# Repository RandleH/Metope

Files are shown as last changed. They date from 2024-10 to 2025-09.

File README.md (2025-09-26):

# Metope

<p align="center"> 
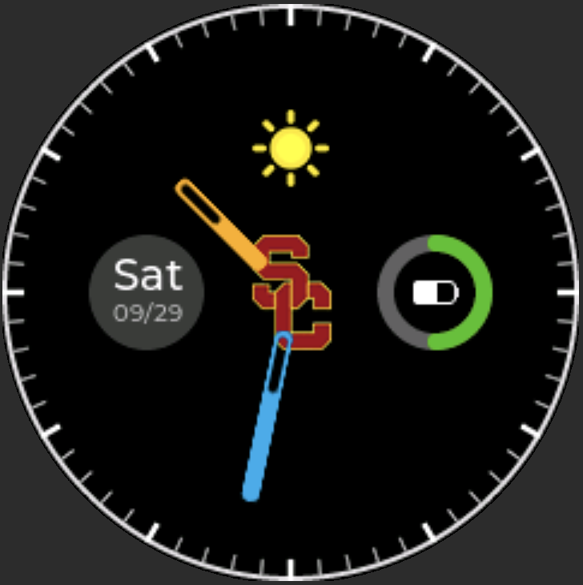
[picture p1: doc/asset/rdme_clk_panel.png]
rdme_clk_panel
    
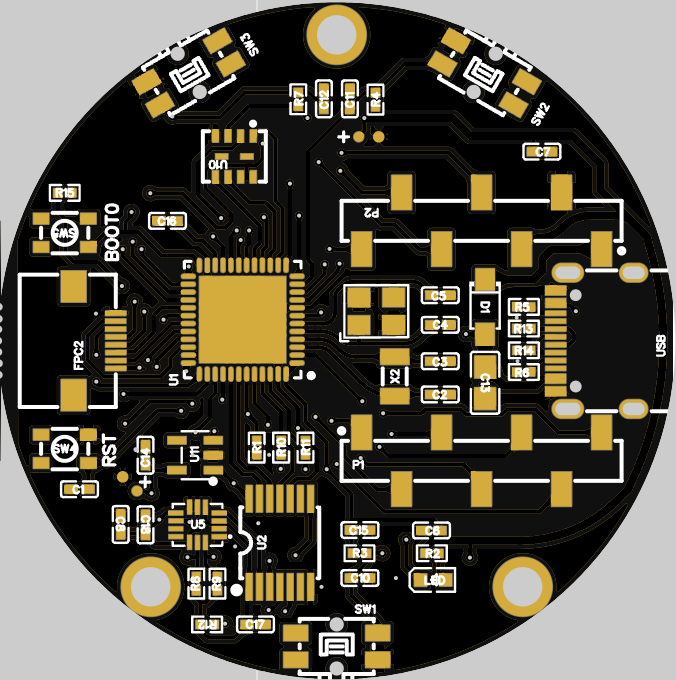
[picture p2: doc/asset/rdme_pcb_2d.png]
rdme_pcb_2d
   
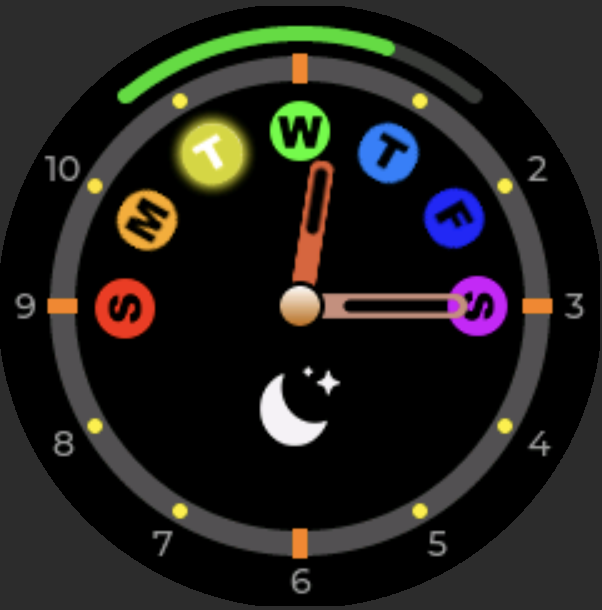
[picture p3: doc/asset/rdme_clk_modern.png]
rdme_clk_modern
    
</p>

Metope is a project for a smart digital watch system running on the STM32 target.

## Overview

<p align="center"> <img src="doc/asset/rdme_hierarchy.jpg" alt="rdme_clk_panel" ;" /> </p>

Color Capsule contributes to the firmware program. Grey rectangulars are only the auxiliary components.

## Requirement

- `CMake>=3.19.2`
- `make==3.81`
- `pyenv==2.6.8          (brew)`
- `pyserial==3.5         (pip package)`
- `pyserial-asyncio==0.6 (pip package)`

Metope project dosen't require to install the `arm-gnu-tool-chain` on the host system. Tool chain will be provided via `lib/arm-toolchain`

## Workspace Setup

Clone the workspace

```bash
git clone https://github.com/RandleH/Metope.git
```

This chapter only provides one of the recommended way to set up the project. For more details, please visit [here]().

Deploy the environment

```bash
source setup.env
```

> Target: `STM32F411CEU6`

Compile

```bash
sh rebuild.sh
```

The output files will be the following items:

- `build/model1.elf` - Executable Linkable File
- `build/model1.hex` - Hex file for USART download
- `build/model1.bin` - Compact binary to flash the target memory

## Compilation

Metope has a bash script for the convenience of compilation. Please take reference for `Compilation Configuration Zone` in `rebuild.sh`.

<p align="center"> <img src="doc/asset/rdme_config.jpg" alt="rdme_clk_panel" ;" /> </p>

Here are some typical configurations. Copy the command and replace the one in `rebuild.sh` in the `Compilation Configuration Zone`

### C Make Flag Table

| Keyword \ Allowed Value | 0 | 1 | 2 | Debug | Release |
| --- | --- | --- | ---- | ----- | --- |
| CMAKE_BUILD_TYPE | | | | $√$ | $√$ |
| LOG_LEVEL | **$√$** | $√$ | $√$  | | |
| QMI8658A | | **$\color{green}(√)$** | | | |
| QMI8658C | | $\color{green}(√)$ | | | |
| MPU6050 | | $\color{green}(√)$ | | | |
| UNIT_TEST | | $\color{cyan}(√)$ | | | |
| INCLUDE_TB_OS | $\color{cyan}[√]$ | $\color{cyan}[√]$ | | | |
| INCLUDE_TB_BSP | $\color{cyan}[√]$ | $\color{cyan}[√]$ | | | |
| INCLUDE_TB_CMN | $\color{cyan}[√]$ | $\color{cyan}[√]$ | | | |

### Environment Setup

#### STM32F411CEU6

>```bash
>source setup.env
>```
>
>Or 
>
>```bash
>source setup.env STM32F411CEU6
>```

#### STM32F405RGT6

```bash
source setup.env STM32F405RGT6
```

#### Native

```bash
source setup.env native
```

This native mode will use your local compiler to partially build the project. This is for the purpose of experiment to test non-machine dependent code.

Note that the main entrance of native program is different than others.

- Native Program: `${PRJ_TOP}/artifacts/main_native.cc`
- Target Program: `${PRJ_TOP}/artifacts/main_program.cc`
- Emulator Program: `${PRJ_TOP}/artifacts/main_emulator.cc`

### Firmware (Debug)

```bash
mkdir build
cd ./build
cmake -DCMAKE_BUILD_TYPE=<value> [-DLOG_LEVEL=<value>] .. && make -j12
```

> Example:
>
> ```
> cmake -DCMAKE_BUILD_TYPE=Debug -DLOG_LEVEL=2 .. && make -j12
> ```
>
> ```
> cmake -DCMAKE_BUILD_TYPE=Debug -DLOG_LEVEL=0 .. && make -j12
> ```

### Firmware (Release)

```bash
mkdir build
cd ./build
cmake -DCMAKE_BUILD_TYPE=Release .. && make -j12
```

### Test Bench (CI)

```bash
mkdir build
cd ./build
cmake -DCMAKE_BUILD_TYPE=Debug -DUNIT_TEST=1 -DINCLUDE_TB_BSP=1 -DINCLUDE_TB_CMN=1 .. && make -j12
```

## Debug

### Vscode

Step 0: Always deploy the environment first.

> ```bash
> source setup.env
> ```
>
> The `.vscode` will be updated here depending on your OS.

Step 1: Install the Vscode extension `Cortex-Debug`

Step 2: Install `J-Link` tools

>```bash
>brew install --cask segger-jlink
>```

Step 3: Select a specific debugging mode

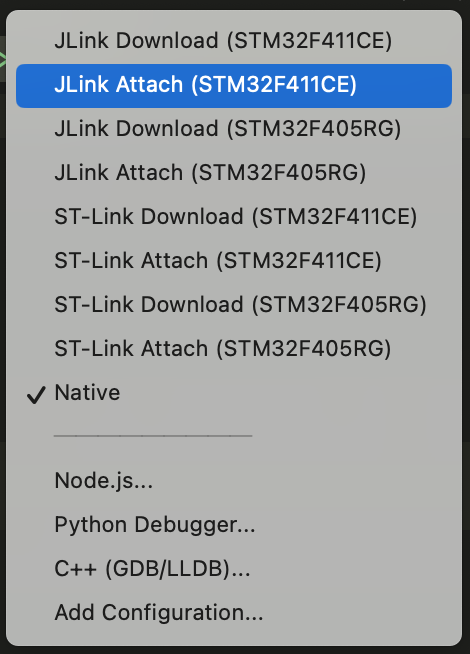
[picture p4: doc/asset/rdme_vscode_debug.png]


>- `JLink Download` - Download the program to target. You need to compile the project first.
>
>- `JLink Attach` - Attach to the program without downloading. Again you need to compile first.
>
>- `STLink Download` - Same as the J-Link but use ST-Link Port
>
>- `STLink Attach` - Same as the J-Link but use ST-Link Port
>
>- `Native` - This will call native cppdbg. Make sure you have your local compiler installed
>
>- `Emulator` - Run the program via qemu emulator environment

## Analog Clock

The angle of hour needle and minute needle has the following property.

Let $\alpha$ be the hour needle angle and $\beta$ be the minute needle angle, where $\alpha,\beta \in [0:3599]$.

$$
\frac{\beta}{12}= \Delta\alpha
$$

> (1)

$$
\Delta\alpha=\alpha \mod{\frac{3600}{12}}
$$

> (2)

Note  $\xi_{\alpha}$ and $\xi_{\beta}$ be the remainder of escaped time in microseconds. Then

$$
t_{\Delta\alpha} = \Delta\alpha \cdot12000 + \xi_{\alpha}
$$
> (3) where $t_{\Delta\alpha}$ is represented in microseconds

$$
t_{\beta} = \beta \cdot 1000 + \xi_{\beta}
$$
> (4) where $t_{\Delta\beta}$ is represented in microseconds. 

$$
t_{\Delta\alpha} = t_{\Delta\beta}
$$

> (5) The escaped time should always the same.

Therefore `(2)` `(3)` `(4)` `(5)` $\Rightarrow$ `(6)`.

$$
12000 \cdot \left( \alpha \mod{\frac{3600}{12}} \right) + \xi_{\alpha} = \beta \cdot 1000 + \xi_{\beta}
$$

> (6)

Check more details on [desmos](https://www.desmos.com/calculator/9qkivl2gf6),. A live diagram explains a lot.

## Code Conduct

I'd appreciate everybody's efforts to maintain a good, high quality coding environment. Good coding habit increased readability and minimized the bugs. In this project, there are a set of rules on code format.

### Code Section

```c
/* ************************************************************************** */
/*                                    XXXX                                    */
/* ************************************************************************** */
```

### Function

```c
/**
 * @brief Description
 * @param [in]    arg1 - xxxx
 * @param [inout] arg2 - xxxx
 * @param [out]   arg3 - xxxx
 * @return xxxx
 */
int foo( int arg1, int arg2, int arg3){
  // body //
}
```

> Each function must have `brief` | `param` (if exists) | `return` (if exists) in doxygen style.

### Safe Zone Banner

```c
///////////////////////////////////////////////////////////////
/////////////////////// Safe Zone Start ///////////////////////

//////////////////////// Safe Zone End ////////////////////////
///////////////////////////////////////////////////////////////
```

### File Header

```c
/**
 ******************************************************************************
 * @file    xxxx.c
 * @author  RandleH
 * @brief   xxxx
 ******************************************************************************
 * @attention
 *
 * Copyright (c) 2022 RandleH.
 * All rights reserved.
 *
 * This software component is licensed by RandleH under BSD 3-Clause license,
 * the "License"; You may not use this file except in compliance with the
 * License. You may obtain a copy of the License at:
 *                        opensource.org/licenses/BSD-3-Clause
 *
 ******************************************************************************
*/
```

### C Compilation Indication

```c++
#ifdef __cplusplus
extern "C"{
#endif

#ifdef __cplusplus
}
#endif
```

## Python Environment Setup

### Create pyenv folder

If the following directory doesn't exist, make one.
```
mkdir ~/.pyenv
mkdir ~/.pyenv/versions/
```

### Link Python
Link python package to the one installed by brew
```
ln -s $(brew --cellar python)/* ~/.pyenv/versions/
```

### Install Python
It's better to install the python via pyenv. More user friendly when switching to either local or global.
```
brew install libxml2 libxslt
pyenv install 3.11.5
```

## Lesson Learnt

Sep 3rd, 2025
>Register SR got cleared when inserting a breakpoint in the handler. Consequently the system can not recognize the new RX message because the SR register was cleared.
>
>Do not add the break point ahead of the program reading the register. Because reading the register value means something else in the embedded system. It may clear the internal bits by hardware. Your debugger will sceiently read those value causing register value cleared and this may impact your callflow.

## Utility

- [**Online GDB**](https://www.onlinegdb.com/)
- [**Simulator**](https://wokwi.com)
- [**Hex Viewer**](https://hexed.it)

## Reference

- [**Datasheet - SpeedStudio Round LCD V1.1** ](https://files.seeedstudio.com/wiki/round_display_for_xiao/SeeedStudio_Round_Display_for_XIAO_v1.1_SCH_230407.pdf)
- [**Programming Manual - STM32F4**](https://www.st.com/resource/en/programming_manual/pm0214-stm32-cortexm4-mcus-and-mpus-programming-manual-stmicroelectronics.pdf)
- [**Reference Manual - STM32F405RGT6**](https://www.st.com/resource/en/reference_manual/dm00031020-stm32f405-415-stm32f407-417-stm32f427-437-and-stm32f429-439-advanced-arm-based-32-bit-mcus-stmicroelectron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)
- [**Reference Manual - STM32F411CEU6**](https://www.st.com/resource/en/reference_manual/rm0383-stm32f411xce-advanced-armbased-32bit-mcus-stmicroelectronics.pdf)
- [**Datasheet - STM32F405RGT6**](https://www.st.com/resource/en/datasheet/stm32f405rg.pdf)
- [**Datasheet - STM32F411CEU6**](https://www.st.com/resource/en/datasheet/stm32f411ce.pdf)
- [**Datasheet - QMI8658A**](https://www.qstcorp.com/upload/pdf/202301/13-52-25%20QMI8658A%20Datasheet%20Rev%20A.pdf)
- [**Datasheet - W25Q32**](https://mm.digikey.com/Volume0/opasdata/d220001/medias/docus/5059/W25Q32JV_RevI_5-4-21.pdf)

- [**Datasheet - LSF0204x**](https://www.ti.com/lit/ds/symlink/lsf0204d.pdf?ts=1733701959935)

- [**IAR Compiler Guide**](https://wwwfiles.iar.com/AVR/webic/doc/EWAVR_CompilerGuide.pdf)

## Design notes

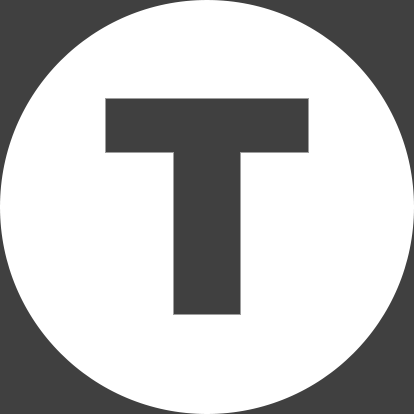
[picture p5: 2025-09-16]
sqlstudio/assets/T.png

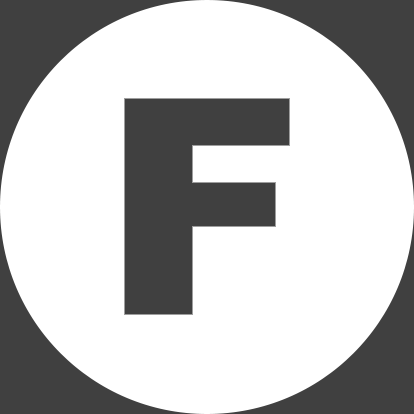
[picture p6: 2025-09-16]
sqlstudio/assets/F.png

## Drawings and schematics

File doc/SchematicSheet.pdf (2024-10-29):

PB15

# NRST PC¹⁴

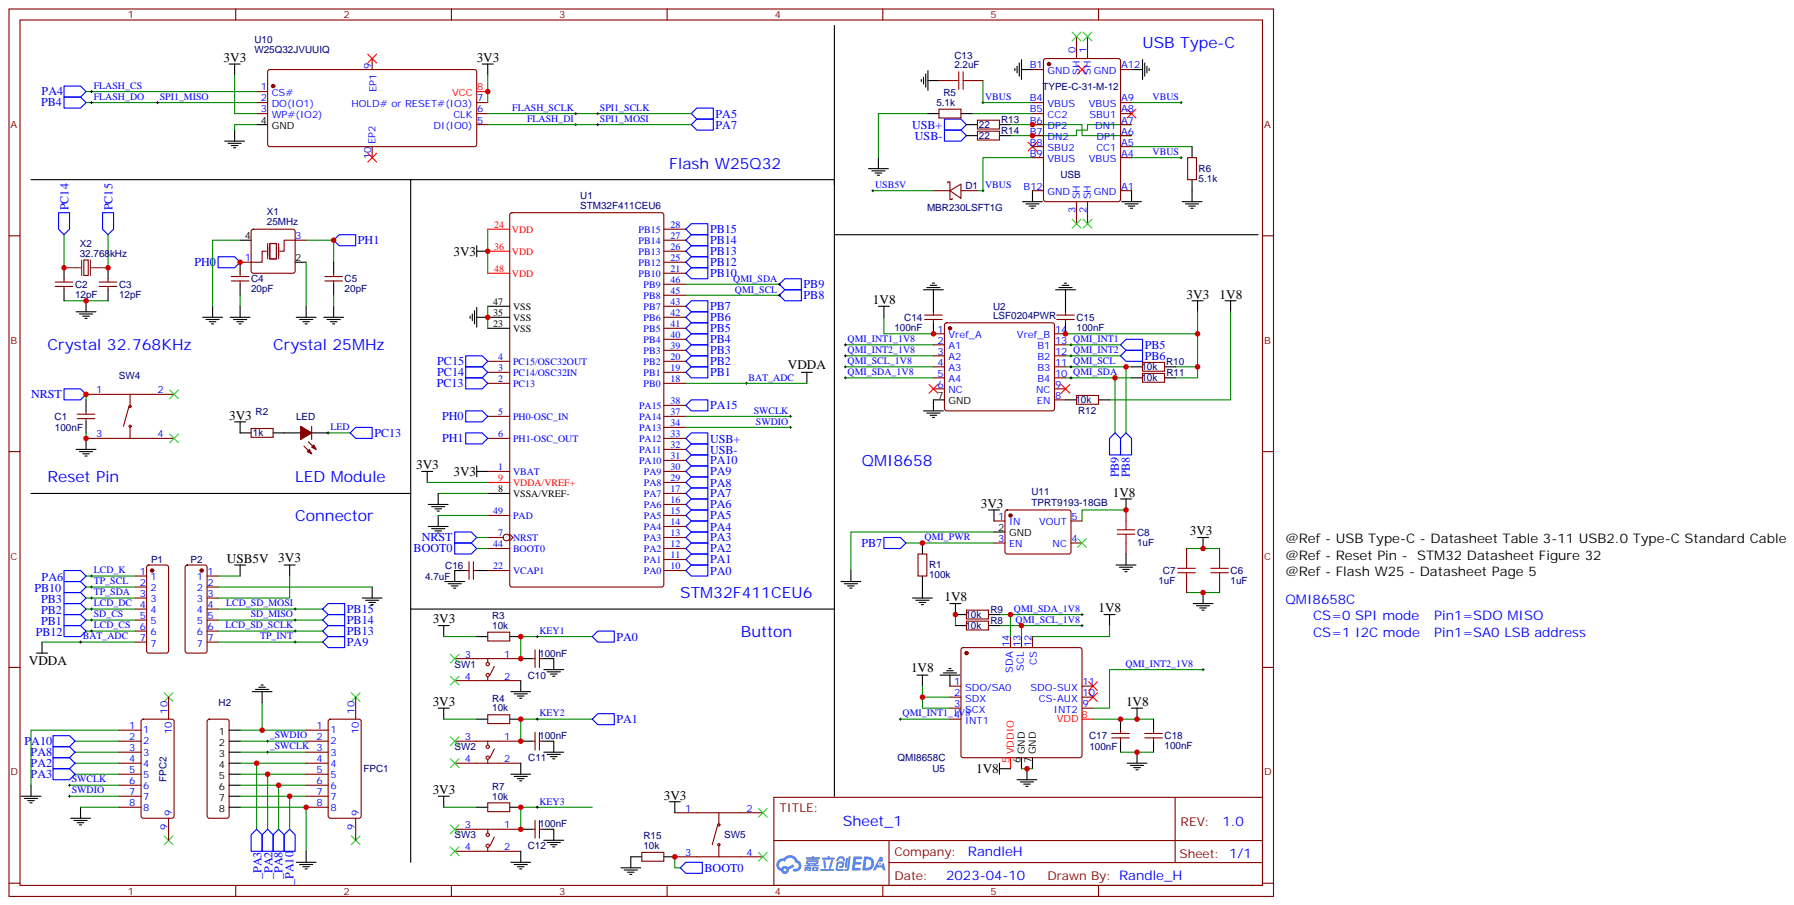
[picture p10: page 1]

@Ref - USB Type-C - Datasheet Table 3-11 USB2.0 Type-C Standard Cable
@Ref - Reset Pin - STM32 Datasheet Figure 32
@Ref - Flash W25 - Datasheet Page 5
QMI8658C
CS=0 SPI mode

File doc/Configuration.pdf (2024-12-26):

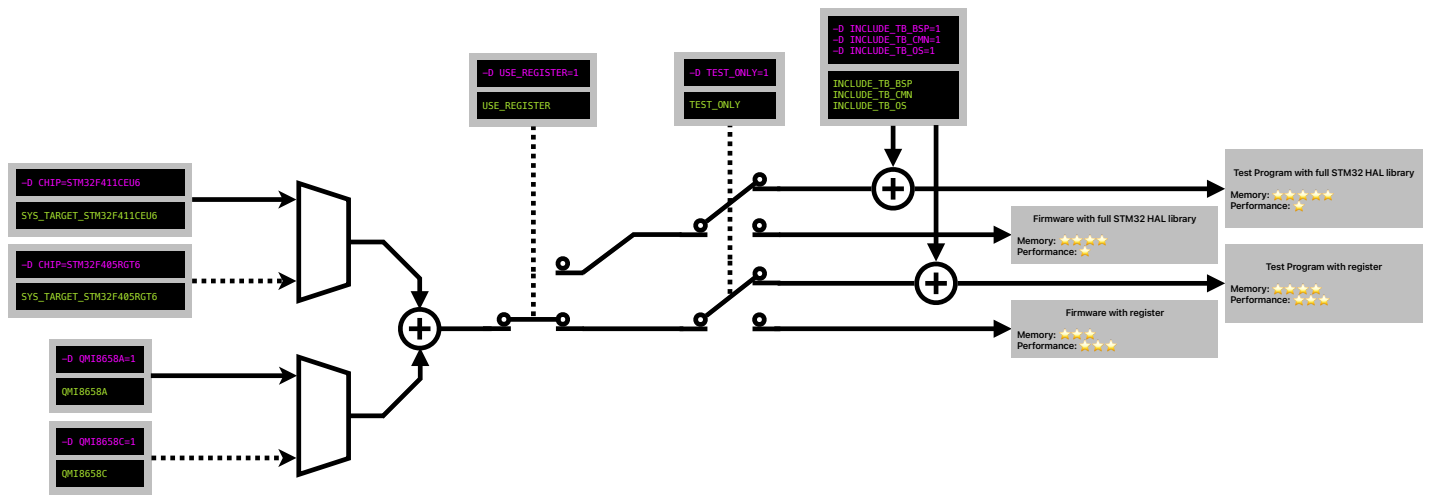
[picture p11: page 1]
-D CHIP=STM32F411CEU6; SYS_TARGET_STM32F411CEU6; -D CHIP=STM32F405RGT6; SYS_TARGET_STM32F405RGT6; -D USE_REGISTER=1; USE_REGISTER; -D TEST_ONLY=1; TEST_ONLY; -D QMI8658A=1; QMI8658A; -D QMI8658C=1; QMI8658C; -D INCLUDE_TB_BSP=1 -D INCLUDE_TB_CMN=1 -D INCLUDE_TB_OS=1; INCLUDE_TB_BSP INCLUDE_TB_CMN INCLUDE_TB_OS; Memory: ⭐ ⭐ ⭐ ⭐ ⭐ Performance: ⭐; Memory: ⭐ ⭐ ⭐ ⭐ Performance: ⭐; Memory: ⭐ ⭐ ⭐ ⭐ Performance: ⭐ ⭐ ⭐; Memory: ⭐ ⭐ ⭐ Performance: ⭐ ⭐ ⭐

Test Program with full STM32 HAL library

Firmware with full STM32 HAL library

Test Program with register

Firmware with register

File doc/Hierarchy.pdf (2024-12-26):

# cmn

# bsp

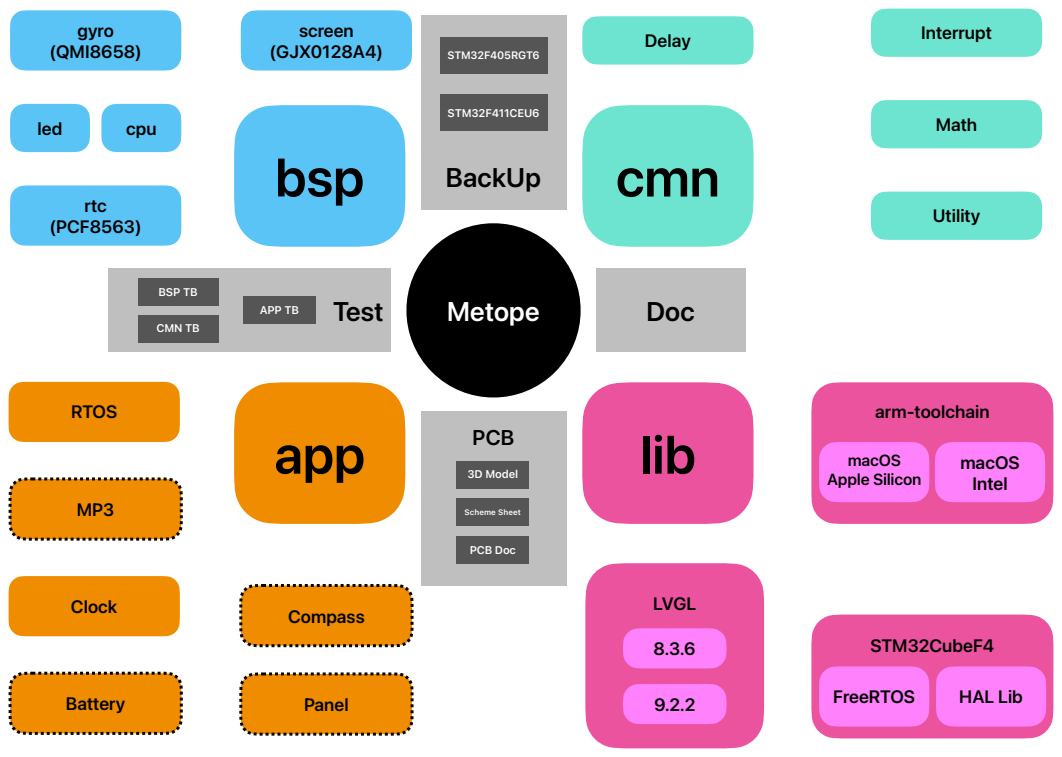
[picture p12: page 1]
STM32CubeF4; arm-toolchain; LVGL; lib; FreeRTOS; HAL Lib; macOS Apple Silicon; macOS Intel; Delay; Interrupt; Math; Utility; cpu; gyro (QMI8658); led; rtc (PCF8563); screen (GJX0128A4); app; RTOS; Clock; Compass; Battery; Panel; Test; Metope; Doc; BackUp; PCB; BSP TB; CMN TB; APP TB; STM32F405RGT6; STM32F411CEU6; 3D Model; Scheme Sheet; PCB Doc

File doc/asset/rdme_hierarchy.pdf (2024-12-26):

# cmn

# bsp

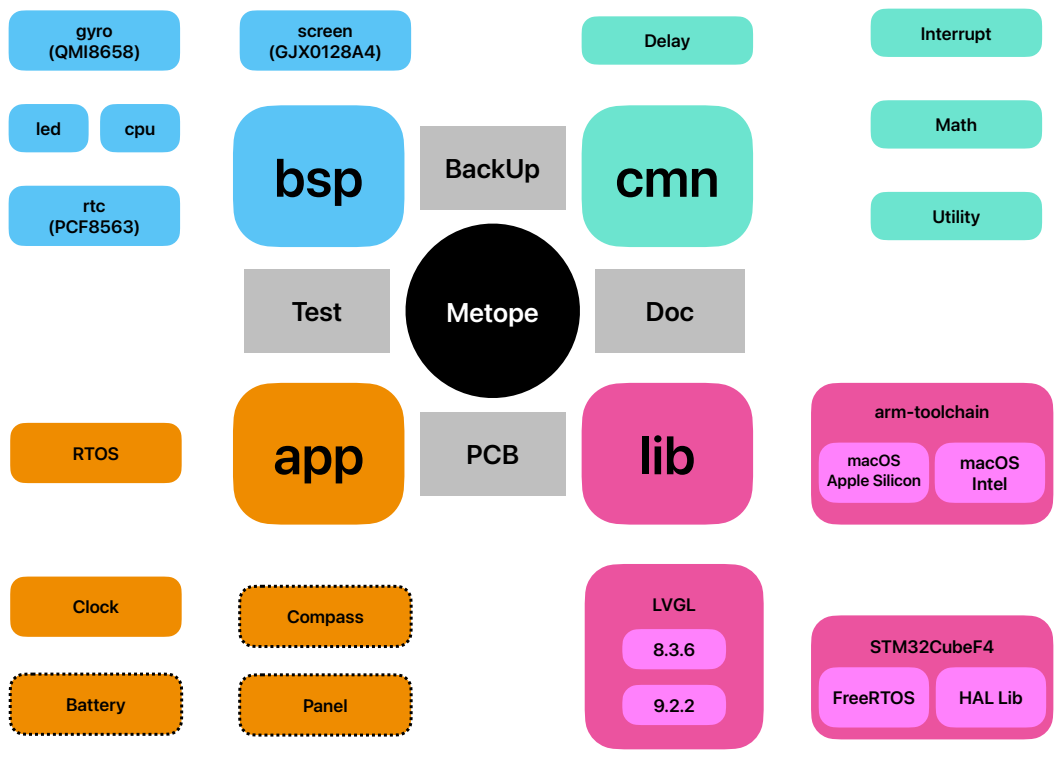
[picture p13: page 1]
STM32CubeF4; arm-toolchain; LVGL; lib; FreeRTOS; HAL Lib; macOS Apple Silicon; macOS Intel; Delay; Interrupt; Math; Utility; cpu; gyro (QMI8658); led; rtc (PCF8563); screen (GJX0128A4); RTOS; app; Clock; Compass; Battery; Panel; Test; Metope; Doc; BackUp; PCB

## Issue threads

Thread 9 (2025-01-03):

Clock Pattern Mismatched

RandleH, 2025-01-03:
See details in the `app_gui.c`
> ```
> ASSERT( minute_in_ms_total == delta_hour_in_ms_total, "Needle Pattern Mismatched");
> ```

From the trace log, the minute and hour degrees variable was accidentally overwritten in somewhere else.

```
ms=75 H_rem=5075 M_rem=75 H_deg=3106 M_deg=1277 h'_ms=1272000 m_ms=1277000 H'_ms=1277075 M_ms=1277075
ms=75 H_rem=5150 M_rem=150 H_deg=3106 M_deg=1277 h'_ms=1272000 m_ms=1277000 H'_ms=1277150 M_ms=1277150
ms=75 H_rem=5225 M_rem=225 H_deg=3106 M_deg=1277 h'_ms=1272000 m_ms=1277000 H'_ms=1277225 M_ms=1277225
ms=75 H_rem=5300 M_rem=300 H_deg=3106 M_deg=1277 h'_ms=1272000 m_ms=1277000 H'_ms=1277300 M_ms=1277300
ms=75 H_rem=5375 M_rem=375 H_deg=3106 M_deg=1277 h'_ms=1272000 m_ms=1277000 H'_ms=1277375 M_ms=1277375
ms=75 H_rem=5450 M_rem=450 H_deg=3106 M_deg=1277 h'_ms=1272000 m_ms=1277000 H'_ms=1277450 M_ms=1277450
ms=75 H_rem=5525 M_rem=525 H_deg=3106 M_deg=1277 h'_ms=1272000 m_ms=1277000 H'_ms=1277525 M_ms=1277525
ms=75 H_rem=5600 M_rem=600 H_deg=3106 M_deg=1277 h'_ms=1272000 m_ms=1277000 H'_ms=1277600 M_ms=1277600
ms=75 H_rem=5675 M_rem=675 H_deg=3106 M_deg=1277 h'_ms=1272000 m_ms=1277000 H'_ms=1277675 M_ms=1277675
ms=75 H_rem=5750 M_rem=750 H_deg=3106 M_deg=1277 h'_ms=1272000 m_ms=1277000 H'_ms=1277750 M_ms=1277750
ms=75 H_rem=5825 M_rem=825 H_deg=3106 M_deg=1277 h'_ms=1272000 m_ms=1277000 H'_ms=1277825 M_ms=1277825
ms=75 H_rem=5900 M_rem=900 H_deg=3106 M_deg=1277 h'_ms=1272000 m_ms=1277000 H'_ms=1277900 M_ms=1277900
ms=75 H_rem=5975 M_rem=975 H_deg=3106 M_deg=1277 h'_ms=1272000 m_ms=1277000 H'_ms=1277975 M_ms=1277975
ms=75 H_rem=6050 M_rem=50 H_deg=3106 M_deg=1278 h'_ms=1272000 m_ms=1278000 H'_ms=1278050 M_ms=1278050
ms=75 H_rem=6125 M_rem=125 H_deg=3106 M_deg=1277 h'_ms=1272000 m_ms=1277000 H'_ms=1278125 M_ms=1277125

Assertion@/Users/yuanjiqiu/Desktop/Metope/app/app_gui.c:339
Needle Pattern Mismatched
```

The `M_deg` was unexpectedly change back to `1277`.

Checked the angle calculation. Result was correct.

Clock pattern simulation is available on [here](https://www.desmos.com/calculator/yhxkqm7rup)

RandleH, 2025-01-04:
## Analysis

Issue was caused by unprotected shared resource designed.

We have `app_gui_update_modulo()` and `app_gui_clock_main()` running in two threads.
Both functions have R/W access to the clock parameters.

Note that in `app_gui_update_modulo()`:
```
pClient->_degree_hour %= 3600
pClient->_degree_minute %= 3600
```
Modulo is NOT an atomic operation.

Besides `app_gui_update_modulo ()` is on the idle thread, which would have the lowest priority in tasks.

## Solution

- For each clock style, create `init()` | `inc()` | `set()` | `idle()` | `deinit()` methods.
-- `idle()` will run on the FreeRTOS idle task.
- For clock private parameters, it will be allocated on the `p_anything` pointer.
- Add mutex for clock private parameters.

Closed 2025-01-04.

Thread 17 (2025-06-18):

Add Sleep Mode and Low Power Mode

RandleH, 2025-06-18:
- STM32 Support the WakeUp Key A0
- Deep sleep mode. Only the external RTC module is running.

RandleH, 2025-06-20:
Entering low-power mode:
- Disable unnecessary peripherals.
- Gating the clocks to the APBx and AHBx peripherals when they are unused.
- Slowing down the system clocks
- Low-power modes are entered by the MCU by executing the WFI (Wait For Interrupt), or WFE (Wait for Event) instructions, or when the SLEEPONEXIT bit in the Cortex®-M4 with FPU System Control register is set on Return from ISR.

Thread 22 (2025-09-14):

Noise from USART can cause an assertion

RandleH, 2025-09-14:
**Issue**
- The command box will parse the string buffer after the rx interrupt even when a noise occurred.

**Action Item**
- Please add the error code handler for this.
- Make assertion for the invalid command only in DEBUG mode.

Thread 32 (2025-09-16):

App cmdbox message process bugs.

RandleH, 2025-09-16:
It is per interrupt per character. Each ISR call will unblock the cmdbox_main and flush the buffer W/WO checking the new_msg or not.

RandleH, 2025-09-17:
```
ASSERT( (*cmd_end == '\0'), "Command string must be null terminated!!");
```

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

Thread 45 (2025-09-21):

Add GDB listener script

RandleH, 2025-09-21:
Once connected the target, add GDB listener to trace the status. If watch dog is missing or hardfault handler was detected, generate the core dump and commit to a new branch automatically.

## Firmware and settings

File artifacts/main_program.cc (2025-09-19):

/**
 ******************************************************************************
 * @file    main_program.cc
 * @author  RandleH
 * @brief   Main program entrance
 ******************************************************************************
 * @attention
 *
 * Copyright (c) 2022 RandleH.
 * All rights reserved.
 *
 * This software component is licensed by RandleH under BSD 3-Clause license,
 * the "License"; You may not use this file except in compliance with the
 * License. You may obtain a copy of the License at:
 *                        opensource.org/licenses/BSD-3-Clause
 *
 ******************************************************************************
*/


/* ************************************************************************** */
/*                                  Includes                                  */
/* ************************************************************************** */
#include "init.h"
#include "global.h"
#include "assert.h"
#include "trace.h"
#include "cmn_type.h"
#include "bsp_led.h"
#include "app_rtos.h"
#include "cmn_delay.h"


#ifdef __cplusplus
extern "C"{
#endif

int main(int argc, char *argv[]){
  
  /**
   * @note
   *  Hardware Initialization
   *  @cpu: CortexM4 STM32F411CEU6 96MHz
   *  @timer: SYSTICK=84MHz APB1=96MHz APB2=96MHz 
   *  @periphral: AHB=96MHz APB1=48MHz APB2=96MHz USB=48MHz HSE=25MHz LSE=32.768KHz
   * 
   *  @cpu: CortexM4 STM32F405RGT6 84MHz
   *  @timer: SYSTICK=84MHz APB1=84MHz APB2=84MHz 
   *  @periphral: AHB=84MHz APB1=42MHz APB2=84MHz HSE=25MHz LSE=32.768KHz
   * 
  */
  hw_init();
  data_init();
  bsp_init();
  app_init();
  os_init();

  TRACE_INFO("System boot completed.");

#if 1
  {
    const volatile uint32_t REG_SCB_CPUID = SCB->CPUID;
    TRACE_DEBUG("Processor Manufacturer Info:");
    TRACE_DEBUG("+------------------------------------------------------+");
    TRACE_DEBUG("| Implementer | Variant | Constant | PartNo | Revision |");
    TRACE_DEBUG("|-------------+---------+----------+--------+----------|");
    TRACE_DEBUG("| 0x%02X        | 0x%02X    | 0x%01X      | 0x%03X  | 0x%01X      |",\
      ((REG_SCB_CPUID & SCB_CPUID_IMPLEMENTER_Msk ) >> SCB_CPUID_IMPLEMENTER_Pos ),\
      ((REG_SCB_CPUID & SCB_CPUID_VARIANT_Msk     ) >> SCB_CPUID_VARIANT_Pos     ),\
      ((REG_SCB_CPUID & SCB_CPUID_ARCHITECTURE_Msk) >> SCB_CPUID_ARCHITECTURE_Pos),\
      ((REG_SCB_CPUID & SCB_CPUID_PARTNO_Msk      ) >> SCB_CPUID_PARTNO_Pos      ),\
      ((REG_SCB_CPUID & SCB_CPUID_REVISION_Msk    ) >> SCB_CPUID_REVISION_Pos    ) \
    );
    TRACE_DEBUG("+------------------------------------------------------+");
    TRACE_DEBUG("\n");
    UNUSED(REG_SCB_CPUID);
  }
#endif

#if 1
  {
    const volatile uint32_t REG_SCB_AIRCR = SCB->AIRCR;
    TRACE_DEBUG("Application Interrupt Reset Control Register:");
    TRACE_DEBUG("\tis_little_endian         %d", ((REG_SCB_AIRCR & SCB_AIRCR_ENDIANESS_Msk) >> SCB_AIRCR_ENDIANESS_Pos));
    TRACE_DEBUG("\tinterrupt_priority_group %d", ((REG_SCB_AIRCR & SCB_AIRCR_PRIGROUP_Msk) >> SCB_AIRCR_PRIGROUP_Pos));
    TRACE_DEBUG("\n");
  }
#endif

#if 1
  {
    const volatile uint32_t *REG_NVIC_ISER = NVIC->ISER;
    TRACE_DEBUG("Nested Vectored Interrupt Controller:");
    TRACE_DEBUG("\tis_irq_enabled   %d", (0 == __get_PRIMASK()));
    TRACE_DEBUG("\tUSART1_IRQn      %d", (0 != (REG_NVIC_ISER[USART1_IRQn     >> 5] & (1 << (USART1_IRQn     & 0x1F)))));
    TRACE_DEBUG("\tWWDG_IRQn        %d", (0 != (REG_NVIC_ISER[WWDG_IRQn       >> 5] & (1 << (WWDG_IRQn       & 0x1F)))));    /*!< Window WatchDog Interrupt                                         */
    TRACE_DEBUG("\tPVD_IRQn         %d", (0 != (REG_NVIC_ISER[PVD_IRQn        >> 5] & (1 << (PVD_IRQn        & 0x1F)))));    /*!< PVD through EXTI Line detection Interrupt                         */
    TRACE_DEBUG("\tTAMP_STAMP_IRQn  %d", (0 != (REG_NVIC_ISER[TAMP_STAMP_IRQn >> 5] & (1 << (TAMP_STAMP_IRQn & 0x1F)))));    /*!< Tamper and TimeStamp interrupts through the EXTI line             */
    TRACE_DEBUG("\tRTC_WKUP_IRQn    %d", (0 != (REG_NVIC_ISER[RTC_WKUP_IRQn   >> 5] & (1 << (RTC_WKUP_IRQn   & 0x1F)))));    /*!< RTC Wakeup interrupt through the EXTI line                        */
    TRACE_DEBUG("\tFLASH_IRQn       %d", (0 != (REG_NVIC_ISER[FLASH_IRQn      >> 5] & (1 << (FLASH_IRQn      & 0x1F)))));    /*!< FLASH global Interrupt                                            */
    TRACE_DEBUG("\tRCC_IRQn         %d", (0 != (REG_NVIC_ISER[RCC_IRQn        >> 5] & (1 << (RCC_IRQn        & 0x1F)))));    /*!< RCC global Interrupt                                              */
    TRACE_DEBUG("\tUSART2_IRQn      %d", (0 != (REG_NVIC_ISER[USART2_IRQn     >> 5] & (1 << (USART2_IRQn     & 0x1F)))));
    TRACE_DEBUG("\tEXTI15_10_IRQn   %d", (0 != (REG_NVIC_ISER[EXTI15_10_IRQn  >> 5] & (1 << (EXTI15_10_IRQn  & 0x1F)))));
    TRACE_DEBUG("\tTIM2_IRQn        %d", (0 != (REG_NVIC_ISER[TIM2_IRQn       >> 5] & (1 << (TIM2_IRQn       & 0x1F)))));
    TRACE_DEBUG("\n");
  }
#endif

#if 1
  {
    const volatile uint32_t REG_RCC_PLLCFGR = RCC->PLLCFGR;
    const volatile uint32_t REG_RCC_CFGR    = RCC->CFGR;
    
    uint32_t PLL_SRC = ((REG_RCC_PLLCFGR & RCC_PLLCFGR_PLLSRC_Msk) >> RCC_PLLCFGR_PLLSRC_Pos);
    uint32_t f_hse = 25000000;  
    uint32_t f_hsi = 16000000; 
    uint32_t PLL_I = PLL_SRC == 0 ? f_hsi : f_hse;
    uint32_t PLL_N = ((REG_RCC_PLLCFGR & RCC_PLLCFGR_PLLN_Msk) >> RCC_PLLCFGR_PLLN_Pos);
    uint32_t PLL_M = ((REG_RCC_PLLCFGR & RCC_PLLCFGR_PLLM_Msk) >> RCC_PLLCFGR_PLLM_Pos);
    uint32_t PLL_P = ((REG_RCC_PLLCFGR & RCC_PLLCFGR_PLLP_Msk) >> RCC_PLLCFGR_PLLP_Pos);
    uint32_t f_pll = (PLL_I / 1000 * PLL_N / PLL_M) / ((PLL_P+1)*2) * 1000;

    uint32_t clk_src = ((REG_RCC_CFGR & RCC_CFGR_SWS_Msk) >> RCC_CFGR_SWS_Pos);
    const char     *MSG_CLK_SRC[4]  = { "HSI", "HSE", "PLL", "N/A" };
    const uint32_t  MSG_CLK_FREQ[4] = { f_hsi, f_hse, f_pll, 0     };

    uint32_t f_sys = MSG_CLK_FREQ[clk_src];
    uint32_t hpre = ((REG_RCC_CFGR & RCC_CFGR_HPRE_Msk) >> RCC_CFGR_HPRE_Pos);
    if (hpre < 0b1000) {
      hpre = 0b0111;
    }
    uint32_t f_ahb = f_sys >> (hpre + 1 - 0b1000);

    uint32_t ppre2 = ((REG_RCC_PLLCFGR & RCC_CFGR_PPRE2_Msk) >> RCC_CFGR_PPRE2_Pos);
    if (ppre2 < 0b100) {
      ppre2 = 0b011;
    }
    uint32_t f_apb2 = f_ahb >> (ppre2 + 1 - 0b100);

    uint32_t ppre1 = ((REG_RCC_PLLCFGR & RCC_CFGR_PPRE1_Msk) >> RCC_CFGR_PPRE1_Pos);
    if (ppre1 < 0b100) {
      ppre1 = 0b011;
    }
    uint32_t f_apb1 = f_ahb >> (ppre1 + 1 - 0b100);

    TRACE_DEBUG("System Clock Info:");
    TRACE_DEBUG("\tHSI                 %d MHz", f_hsi / 1000000);
    TRACE_DEBUG("\tHSE                 %d MHz", f_hse / 1000000);
    TRACE_DEBUG("\tPLL                 %d MHz", f_pll / 1000000);
    TRACE_DEBUG("\tsystem clk source   [%s]", MSG_CLK_SRC[clk_src]);
    TRACE_DEBUG("\tsystem clk freq     %d MHz", f_sys / 1000000);
    TRACE_DEBUG("\tAHB clk freq        %d MHz", f_ahb / 1000000);
    TRACE_DEBUG("\tAPB1 clk freq       %d MHz", f_apb1 / 1000000);
    TRACE_DEBUG("\tAPB2 clk freq       %d MHz", f_apb2 / 1000000);
    TRACE_DEBUG("\n");
  }
#endif

#if 1
  {
    const volatile uint32_t REG_SYSCFG_MEMRMP = SYSCFG->MEMRMP;
    TRACE_DEBUG("System Configuration Ctrl:");
    TRACE_DEBUG("\tmemory mode         %d", ((REG_SYSCFG_MEMRMP & SYSCFG_MEMRMP_MEM_MODE_Msk) >> SYSCFG_MEMRMP_MEM_MODE_Pos));

    metope.bsp._status.tim9 = 1;
    metope.bsp._status.tim2 = 1;
    metope.bsp._status.i2c1 = 1;
    metope.bsp._status.A9   = 1;
    metope.rtos.status->running[0] = 1;
    metope.rtos.status->running[0] = 0;
    metope.bsp.status->tim9[0] = 0;
    metope.bsp.status->tim2[0] = 0;
    metope.bsp.status->i2c1[0] = 0;
    metope.bsp.status->A9[0]   = 0;
    TRACE_DEBUG("\n");
  }
#endif

#if 1
  {
    TRACE_DEBUG("Application Size in bytes:");
    TRACE_DEBUG("\tmetope         %d bytes", sizeof(metope));
    TRACE_DEBUG("\tmetope.bsp     %d bytes", sizeof(metope.bsp));
    TRACE_DEBUG("\tmetope.app     %d bytes", sizeof(metope.app));
    TRACE_DEBUG("\tmetope.rtos    %d bytes", sizeof(metope.rtos));
    TRACE_DEBUG("\n");
  }
#endif

  app_rtos_start();
  while(1);
}

#ifdef __cplusplus
}
#endif

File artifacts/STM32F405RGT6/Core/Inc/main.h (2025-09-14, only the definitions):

#define LED_Pin GPIO_PIN_13
#define LED_GPIO_Port GPIOC
#define KEY_M_Pin GPIO_PIN_0
#define KEY_M_GPIO_Port GPIOA
#define KEY_R_Pin GPIO_PIN_1
#define KEY_R_GPIO_Port GPIOA
#define DBG_TX_Pin GPIO_PIN_2
#define DBG_TX_GPIO_Port GPIOA
#define DBG_RX_Pin GPIO_PIN_3
#define DBG_RX_GPIO_Port GPIOA
#define FLASH_CS_Pin GPIO_PIN_4
#define FLASH_CS_GPIO_Port GPIOA
#define FLASH_SCK_Pin GPIO_PIN_5
#define FLASH_SCK_GPIO_Port GPIOA
#define FLASH_MOSI_Pin GPIO_PIN_7
#define FLASH_MOSI_GPIO_Port GPIOA
#define SCREEN_DC_Pin GPIO_PIN_2
#define SCREEN_DC_GPIO_Port GPIOB
#define SCREEN_SCK_Pin GPIO_PIN_13
#define SCREEN_SCK_GPIO_Port GPIOB
#define SCREEN_MISO_Pin GPIO_PIN_14
#define SCREEN_MISO_GPIO_Port GPIOB
#define SCREEN_MOSI_Pin GPIO_PIN_15
#define SCREEN_MOSI_GPIO_Port GPIOB
#define TP_INT_Pin GPIO_PIN_9
#define TP_INT_GPIO_Port GPIOA
#define KEY_L_Pin GPIO_PIN_15
#define KEY_L_GPIO_Port GPIOA
#define FLASH_MISO_Pin GPIO_PIN_4
#define FLASH_MISO_GPIO_Port GPIOB
#define GYRO_SCK_Pin GPIO_PIN_8
#define GYRO_SCK_GPIO_Port GPIOB
#define GYRO_SDA_Pin GPIO_PIN_9
#define GYRO_SDA_GPIO_Port GPIOB

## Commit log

2024-10-29 CMake success
    [SpeedStudio.kicad_pcb, SpeedStudio.kicad_sch]
2024-10-29 Add stm32f411ceu6
2024-10-29 Fix f405 linker issue
    [STM32F405RGT6.ioc]
2024-10-29 [STABLE] EXTI key-led
    [AltiumDesigner - PCB.pcbdoc, AltiumDesigner - Sheet_1.schdoc, AltiumDesigner - Sheet_2.schdoc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]
2024-10-29 TB_Infra - Phase2: Support inserting tests
2024-10-29 Documentation && Clean Up
    [SpeedStudio.kicad_pcb, SpeedStudio.kicad_sch]
2024-10-30 Add Screen PWM Test
2024-10-30 Screen PWM BKL Test uplodated.
2024-10-31 Add USE_REGISTER for PWM
2024-11-03 Fix core pll clock
    [main.cc]
2024-11-05 Fix LVGL - 8.3.6 + UI Debut + UI Test Bench
    [bsp_screen.c, cmn_type.h, global.cc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]
2024-11-06 DMA Flash SPI
2024-11-06 BUG: Out of Memory - FLASH 101%
    [STM32F411CEU6.ioc, main.c, main.cc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]
2024-11-09 Screen DMA + Polling + HW NSS
2024-11-17 Non-block timer delay TIM2 + TIM9
2024-11-18 Enable screen onoff switch: KEY_M + TIM9 + display flag
2024-11-19 Use non-block callback on DMA
2024-11-23 Add idle task to fix the overflow bug
    [global.cc]
2024-12-06 Initial Prototype - Read/Write Time
2024-12-11 Gyro Initial Code
    Rebase after RTC
2024-12-11 Add Gyro init() but failed (Rebase on RTC)
    [STM32F411CEU6.ioc, bsp_gyro.c, init.c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]
2024-12-15 Qmi8658 (#3)
    * Contineously updating acc & angular
    * Add QMI8658 DMA
    * Gyro Clean Up
    ---------
2024-12-16 Fix RTOS Bug - Systick Handle && Gyro Acc/Gyro Register Reversal && Hook Functions && RTOS Macros
    [cmn_interrupt.c, global.cc, init.c]
2024-12-16 App RTC Update Stage1: Initial Code Upload
2024-12-20 Fix timer bug - Double clear on SR
    [bsp_screen.c, bsp_timer.c, cmn_delay.c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]
2024-12-24 Fix misc bugs && Cleanup (#4)
    * Clean Up && Rename
    * Update backup
    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
    [STM32F411CEU6.ioc, bsp_gyro.c, bsp_rtc.c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]
2024-12-26 Submodule (#5)
    * Add git submodule
    * Add git submodule
    * Update submodule
    * arm toochain supported
    * Add CMake system env host os
    * Override *.so
    * Update submodule arm-toolchain
    * Update setup.env && disable recursive update for arm-toolchain
    * Update env setup
    * Selectively submodule toolchain
    * Remove local dependency nm/size/objdump
    * .
    * Clean up backup
    * Clean up shell script
    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
    [STM32F405RGT6.ioc, STM32F411CEU6.ioc, main.c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]
2025-01-01 Assertion (#7)
    * Add uart u32 integer printing (Prepare for assertion)
    * Add str num convertor utility
    * Add assertion attempt 1
    * Enable Assertion Attempt 2
    * Enable Assertion Attempt 3
    * Adjust uart printf size
    * Remove led toggle for touch screen
    * Clean && Apply Assertion
    * Enable Assertion Capture for needle pattern
    * Fix bugs in angle inc/set
    * Update clock math documentation
    * Update clock math documentation
    * Update clock math documentation
    * Update clock math documentation
    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
    [bsp_gyro.c, bsp_led.c, bsp_screen.c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]
2025-01-03 Move files to top folder (#8)
    * Move files to top folder
    * Selective chip compiling including native
    * Remove generated file && Update setup.env
    * Use generated vscode
    * Do NOT remove generated files
    * Native compiling passed
    * Generalize the vscode setting && Fix bugs in hour rem calculation.
    * Trace + Gyro Delay + Vscode + Surpress Warning
    * Rename FreeRTOS tasks
    * Add example comments for rtc function
    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
    [STM32F405RGT6.ioc, STM32F411CEU6.ioc, bsp_gyro.c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]
2025-01-03 Trace (#10)
    * Add trace level with color printing
    * Add comments
    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
2025-01-05 Analog clock (#12)
    * Generalize analog clock model && add Thread Safe switch
    * Fix timing increasement bugs.
    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
    [global.cc]
2025-01-14 Time adj (#13)
    * Add time auto adjustment
    * Add idle timer thread for App-Clock
    * Add timming difference function
    * Clean up
    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
2025-01-22 Clock UI modern (#15)
    * Redesign clock modern
    * Update readme clock pattern
    * New memory strategy - Use FreeRTOS Realloc
    * Add digits to clock modern
    * Add digits: 11 12 1
    * Update documentation
    * Add color gradient + Battery Display API
    * Add battery adc && Battery Bar Display
    * Disaple DMA Screen(bug) && Fix bugs in bat adc calculation
    * Add more trace
    * Fix battery range
    * Add battery trace log
    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
    [STM32F411CEU6.ioc, bsp_battery.c, bsp_screen.c]
2025-09-06 Cmdbox (#18)
    **Development**
    - Introduce CMN_DATE_YEAR_OFFSET and PCF8563_STARTING_YEAR
    - Support user command: DISPON | DISPOFF | CCW | CW | ST | GT
    - Support native build
    - Initiate the command box database array
    - Add system info printing in the main program
    - Add wrapper functions for malloc / free / realloc
    - Enable the UART RX interrupt mode (CubeMX updated)
    - Support %c in the trace
    - Replace inline structure definitions to typedef
    - Disable battery trace
    - Support ASSERT in native build
    **Documentation**
    - Add lesson learnt chapter
    [STM32F411CEU6.ioc, app_cmdbox.c, bsp_battery.c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]
2025-09-11 Cmdbox bugfix (#20)
    * Fix bugs
    - Fix command starting with number will be mistakenly parsed
    - Fix command containing valid keyword will also be treated valid
    - Fix CI misc
    [app_cmdbox.c, bsp_uart.c, init.c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]
2025-09-14 Prepare for the Jenkins CI plugin (#21)
    * Sketch:
    - Move shell scripts to tool folder.
    - Try with the qemu-system-arm
    * - Add support stm32f405rct6
    * [AnchorPoint] - sh tool/test.sh returns 0
    * Add qemu vscode environment setup
    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
2025-09-14 Uart errhdlr (#26)
    * Add error handler
    * Fix typo
    Issue:
    https://github.com/RandleH/Metope/issues/22
    [app_cmdbox.c, cmn_interrupt.c]
2025-09-14 Cleanup (#27)
    Development
    Unify the CMakeLists.txt
    Rename TEST_ONLY to UNIT_TEST
    Rename INC_DIR_LIST to INC_LIST in cmake.
    Fix LVGL init in app_init(). Function will be called unless it is in emulator mode.
    Switch the order of vscode configuration initialization and submodule download.
    [bsp_gyro.c, bsp_uart.c, cmn_type.h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]
2025-09-16 19 add clock UI switch (#31)
    - Add two abstract layers `app_clock_gui_data_xxxx()` and `app_clock_gui_ctrl_xxxx()`
    - Add SquareLine project files and assets.
    - Add clock style switching. Press key `L` and `R` to switch.
    - Simplify the EXTI key logic.
    - Unify the clock ui sub function. Sub function should ONLY contain ui perspective operations.
    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
2025-09-18 32 app cmdbox message process bugs (#35)
    Add async cmdbox execution
    Disable the interrupt when processing the USART input
    Add TIM9_FLAG for temporary fix
    Add usart.tx_status
    Add application size printing
    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
    [app_cmdbox.c, bsp_timer.c, bsp_uart.c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]
2025-09-19 38 reading bit tim9 tim2 is not atomic operation (#42)
    - Add bit band mapping for bsp/bspscreen/rtos status
    - Add typecasting
    **Note**
    This is for the atomic read operation for 1 bit. If an interrupt happened in the middle of a non atomic bit reading operation, the result will be uncertain.
    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
2025-09-24 33 system core dump support (#46)
    - Add jlink/stlink download script
    - Add hardfault detect program
    - GDB full back trace
    - Memory dump FLASH + SRAM => `${PRJ_TOP}/dbg/outputs`
    **Command**
    - `sh ${PRJ_TOP}/tool/download.sh --adaptor [jlink | stlink]`
    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

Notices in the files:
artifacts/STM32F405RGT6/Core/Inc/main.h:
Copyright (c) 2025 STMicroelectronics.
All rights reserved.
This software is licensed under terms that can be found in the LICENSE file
